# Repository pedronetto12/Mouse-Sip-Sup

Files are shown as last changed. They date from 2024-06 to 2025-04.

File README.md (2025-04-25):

# 🖱️ Mouse Inclusivo Sip-and-Puff

> Um projeto de tecnologia assistiva de **hardware e software abertos**, criado para promover **acessibilidade digital** com baixo custo.

## 💡 Sobre o Projeto

Este repositório apresenta o desenvolvimento de um **mouse controlado por sopro e sucção (Sip-and-Puff)**, pensado para pessoas com comprometimento motor severo e controle de cabeça preservado. O dispositivo permite o controle do cursor e cliques por meio de ações com a boca — como soprar ou sugar — utilizando componentes acessíveis e de baixo custo.

O projeto foi desenvolvido no ambiente universitário, com o objetivo de ser **gratuito, aberto e replicável**, fortalecendo o acesso democrático à tecnologia assistiva no Brasil.

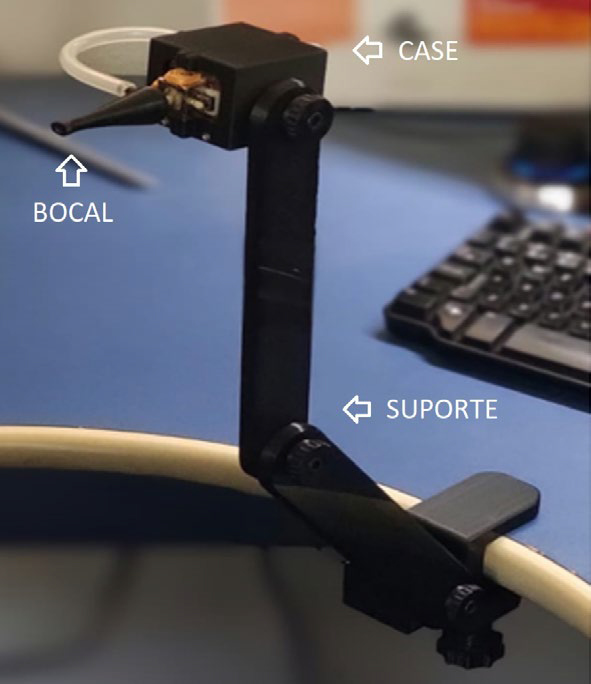
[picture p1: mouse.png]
Mouse Inclusivo Sip-and-Puff


## 🔧 Como Funciona

- **Joystick** detecta o movimento da cabeça do usuário.
- **Sensor de pressão** converte o sopro/sucção em sinais elétricos.
- **Arduino Pro Micro** interpreta os sinais e simula um mouse via USB.

| Ação com a boca | Função no mouse |
|---|---|
| Sopro forte | Clique esquerdo |
| Sucção forte | Clique direito |
| Sopro/sucção leve  | Rolagem de página |

## 📦 Componentes Principais

- Arduino Pro Micro (ATmega32U4)
- Sensor de pressão MPS20N0040D-S
- Módulo joystick KY-023
- Impressão 3D em PLA para a estrutura física

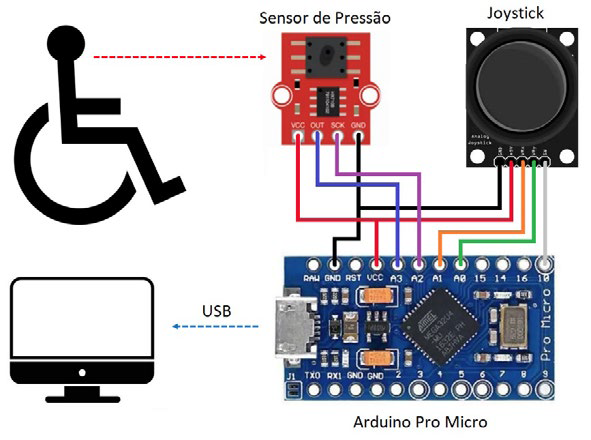
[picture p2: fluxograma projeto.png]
Fluxograma


## 📌 Objetivos

- 🧠 Promover **autonomia** e **inclusão digital**
- 🔓 Ser totalmente **open-source**
- 🤝 Incentivar a **inovação colaborativa**

## 📄 Publicação

Este projeto foi apresentado no **Congresso Brasileiro de Tecnologia Assistiva (CBTA)** como artigo técnico:

> **Grangeiro, Pedro Netto Gandolfi et al.** *Mouse inclusivo de hardware e software aberto controlado por sopro e sucção.* CBTA, 2023.

## 🛠️ Atualização no Design do Bocal

Realizamos uma **melhoria significativa no bocal** do dispositivo. Agora, o mouse conta com:

- 💨 **Ponta substituível**, garantindo mais higiene e praticidade no uso;
- 🦠 **Filtro antibactericida**, promovendo segurança em ambientes clínicos e domiciliares;
- 🔄 Projeto mais modular e de fácil substituição.

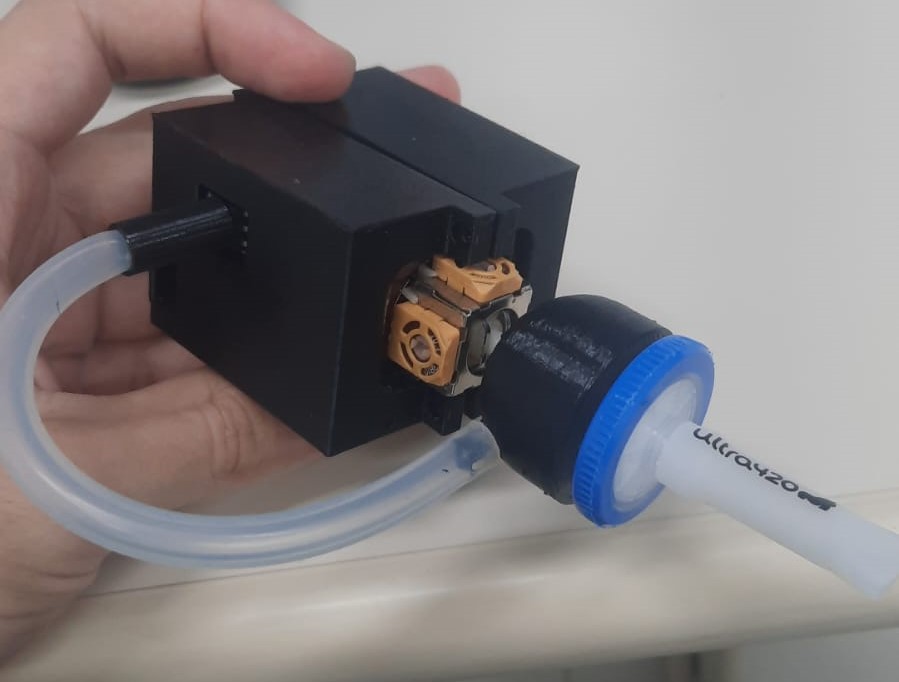
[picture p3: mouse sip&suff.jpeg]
Mouse Atualizado


Essa atualização reforça o compromisso do projeto com a usabilidade, segurança e conforto das pessoas com deficiência que irão utilizá-lo.

## 🤝 Agradecimentos

Agradecimentos à **UDESC** pelo suporte institucional e aos professores e colegas envolvidos.

## 📥 Contribua!

Quer contribuir? Tem ideias para melhorias? Fique à vontade para abrir uma issue ou enviar um pull request! Vamos juntos tornar a tecnologia mais inclusiva 💙

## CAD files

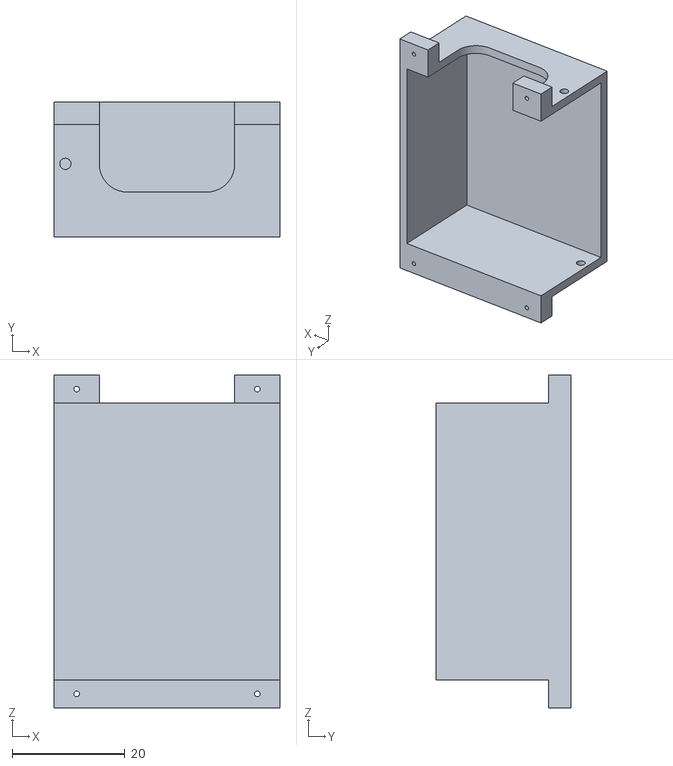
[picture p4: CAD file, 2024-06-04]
Arquivos de impressao mouse sip&sup/encaixe2 mouse.stl
40.0 x 24.0 x 59.0

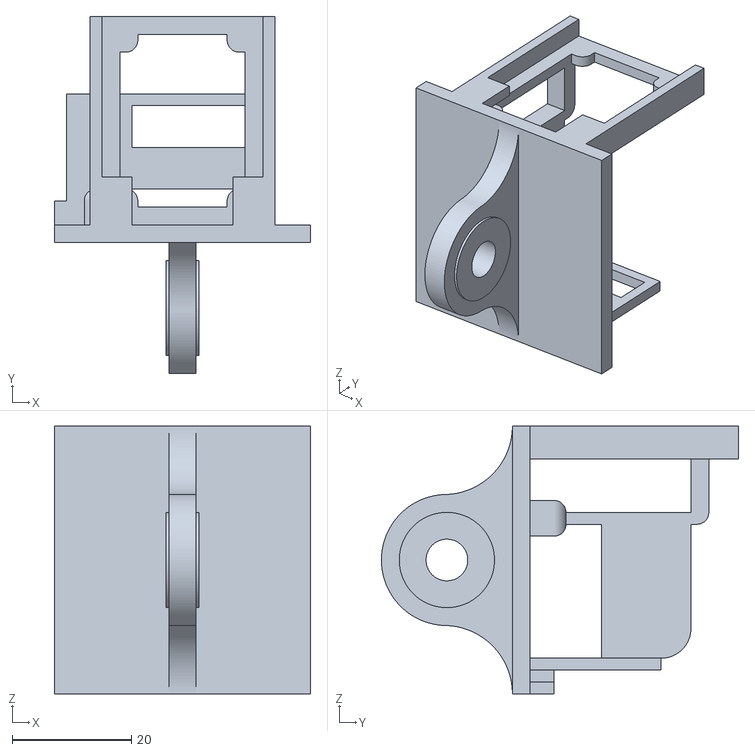
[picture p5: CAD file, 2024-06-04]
Arquivos de impressao mouse sip&sup/base mouse.stl
43.0 x 60.0 x 45.0

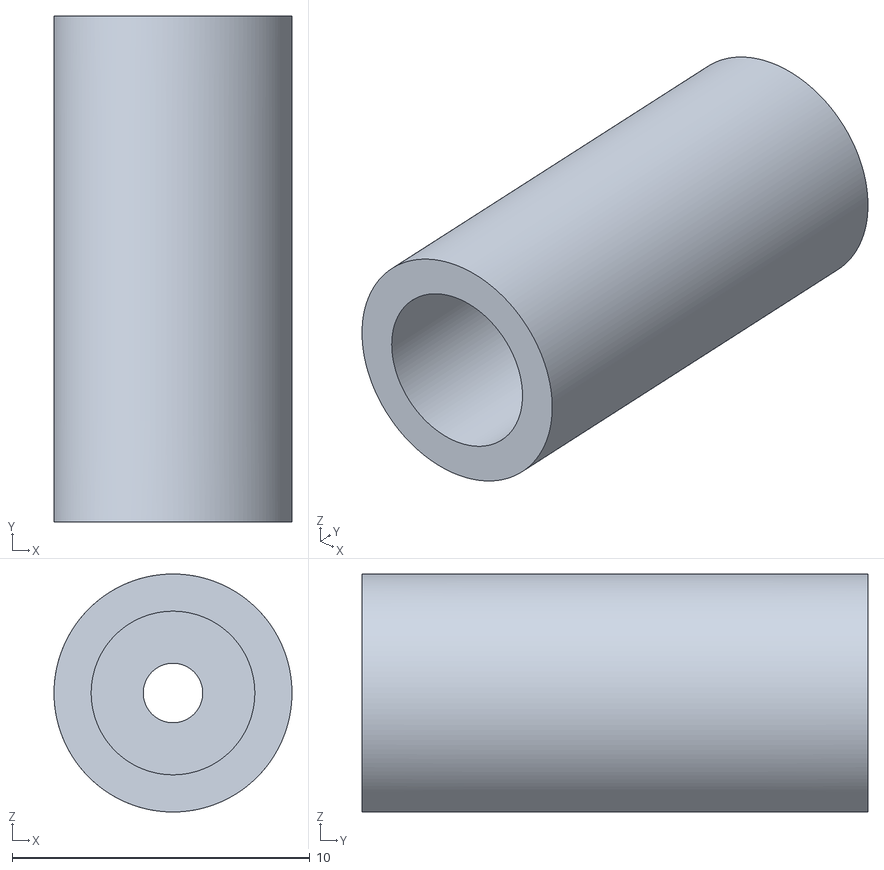
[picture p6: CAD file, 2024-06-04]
Arquivos de impressao mouse sip&sup/conexão tubo mouse.stl
8.00 x 17.0 x 8.00

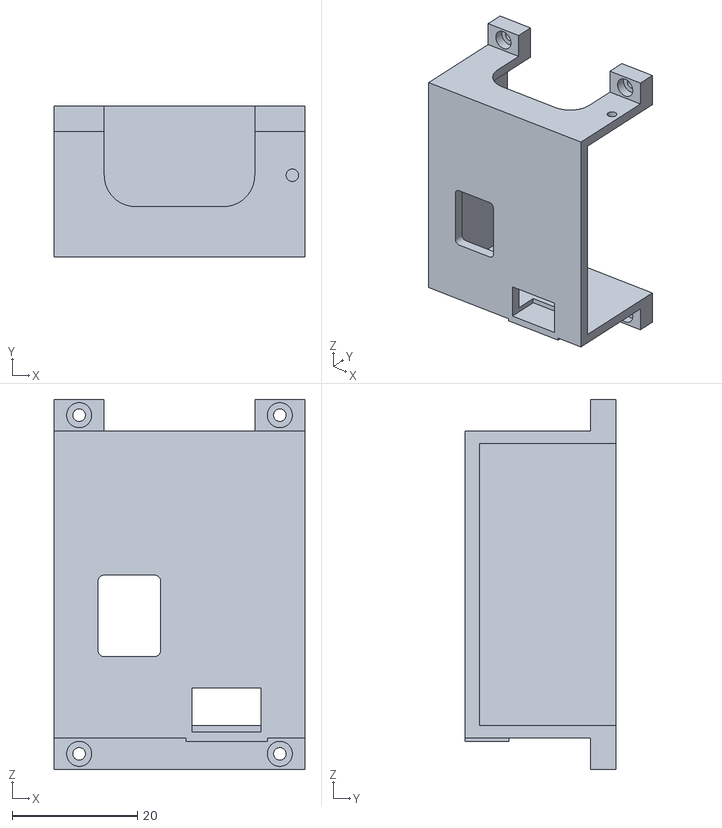
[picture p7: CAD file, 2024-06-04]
Arquivos de impressao mouse sip&sup/encaixe1 mouse.stl
40.0 x 24.0 x 59.0

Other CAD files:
Arquivos de impressao mouse sip&sup/acoplamento joystick.ipt
Arquivos de impressao mouse sip&sup/acoplamento joystick2.ipt
Arquivos de impressao mouse sip&sup/base mouse.ipt
Arquivos de impressao mouse sip&sup/conexão tubo mouse.ipt
Arquivos de impressao mouse sip&sup/encaixe1 mouse.ipt
Arquivos de impressao mouse sip&sup/encaixe2 mouse.ipt

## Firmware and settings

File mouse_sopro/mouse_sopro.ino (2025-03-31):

//----------------------bibliotecas----------------------
#include <Mouse.h>
#include <HX711_ADC.h> //https://github.com/olkal/HX711_ADC
#if defined(ESP8266)|| defined(ESP32) || defined(AVR)
#include <EEPROM.h>
#endif

//pins:
#define AxisX A1
#define AxisY A0
#define led0 3
#define led1 4
#define led2 5
#define led3 6
#define led4 7
#define led5 8
#define led6 9
#define led7 10
#define led8 16
#define led9 14
const int HX711_dout = 2; //mcu > HX711 dout pin, must be external interrupt capable!
const int HX711_sck = 15; //mcu > HX711 sck pin

//HX711 constructor:
HX711_ADC LoadCell(HX711_dout, HX711_sck);

//----------------------Variaveis----------------------
//parametros do HX711
float calibrationValue=2500; // calibration value
unsigned long stabilizingtime = 1000; // tare preciscion can be improved by adding a few seconds of stabilizing time
boolean _tare = true; //set this to false if you don't want tare to be performed in the next step
float dados_sensor=0;
volatile boolean newDataReady;



//parametros do joystick:
int range = 9;            // output range of X or Y movement
int threshold = range / 4;  // resting threshold
int center = range / 2;     // resting position value


//mouse
bool isLeftPressed = false;
bool isRightPressed = false;
int DELAY=0;


//LED
int ledState[10] = {0, 0, 0, 0, 0, 0, 0, 0, 0, 0};

//----------------------funções----------------------
void funcMouse(float ad);
void funcLED(float ad);
void pinLEDs();
void controlLED();
int readAxis(int thisAxis); //função leitura do analogico
void dataReadyISR();

void setup() {
  Serial.begin(57600);
  Serial.println("Starting...");
  LoadCell.setSamplesInUse(1);
  LoadCell.begin(); //config
  Mouse.begin(); //inicia funcionalidade das funções de mouse

  pinLEDs();

  LoadCell.start(stabilizingtime, _tare);//calibração
    if (LoadCell.getTareTimeoutFlag()) {
    Serial.println("Tempo limite, verifique a fiação MCU>HX711 e as designações dos pinos");
    while (1);
  }
  else {  
    LoadCell.setCalFactor(calibrationValue); // set calibration factor (float)
    Serial.println("Startup is complete");
  }
  attachInterrupt(digitalPinToInterrupt(HX711_dout), dataReadyISR, FALLING);
}

void loop() {  
  
  if (newDataReady) {
    newDataReady = 0;
    dados_sensor=LoadCell.getData();
    Serial.print(dados_sensor);
    Serial.print("\t");
    funcMouse(dados_sensor);
    funcLED(dados_sensor);
    controlLED();
  }
  
  Mouse.move(-readAxis(AxisX), readAxis(AxisY), 0);//movimento seta
  delay(10);
}

void funcMouse(float ad){  
 if (ad < -650) { //Hard sip
      if (!isRightPressed) {
        Mouse.press(MOUSE_RIGHT);
        isRightPressed = true;
        Serial.println("ok1");
      }
    } 
    else if (ad >= -650 && ad < -100 ) { //Soft sip
      DELAY++;
      if(DELAY>4){Mouse.move(0, 0, -1);Serial.println("ok2");}
    } 
    else if (ad >= -100 && ad <= 100) { //se estiver no meio, solta os dois botões
      DELAY=0;
      if (isLeftPressed) {Mouse.release(MOUSE_LEFT);isLeftPressed = false;}
      if (isRightPressed) {Mouse.release(MOUSE_RIGHT);isRightPressed = false;}
      Serial.println("ok3");
    } 
    
    else if (ad > 100 && ad <= 650) { //Soft puff
      DELAY++;
      if(DELAY>4){Mouse.move(0, 0, 1);Serial.println("ok4");}
    } 
    
    else if (ad > 650) { //Hard puff
      if (!isLeftPressed) {
        Mouse.press(MOUSE_LEFT);
        isLeftPressed = true;
        Serial.println("ok5");
      }
    }
}

void funcLED(float ad){
  if (ad<=-800){         ledState[0] = 1;ledState[1] = 0;ledState[2] = 0;ledState[3] = 0;ledState[4] = 0;ledState[5] = 0;ledState[6] = 0;ledState[7] = 0;ledState[8] = 0;ledState[9] = 0;}
  if (ad>-800&&ad<=-600){ledState[0] = 1;ledState[1] = 1;ledState[2] = 0;ledState[3] = 0;ledState[4] = 0;ledState[5] = 0;ledState[6] = 0;ledState[7] = 0;ledState[8] = 0;ledState[9] = 0;}
  if (ad>-600&&ad<=-400){ledState[0] = 1;ledState[1] = 1;ledState[2] = 1;ledState[3] = 0;ledState[4] = 0;ledState[5] = 0;ledState[6] = 0;ledState[7] = 0;ledState[8] = 0;ledState[9] = 0;}
  if (ad>-200&&ad<=-50){ ledState[0] = 1;ledState[1] = 1;ledState[2] = 1;ledState[3] = 1;ledState[4] = 0;ledState[5] = 0;ledState[6] = 0;ledState[7] = 0;ledState[8] = 0;ledState[9] = 0;}
  if (ad>-50&&ad<=50){   ledState[0] = 1;ledState[1] = 1;ledState[2] = 1;ledState[3] = 1;ledState[4] = 1;ledState[5] = 0;ledState[6] = 0;ledState[7] = 0;ledState[8] = 0;ledState[9] = 0;}
  if (ad>50&&ad<=200){   ledState[0] = 1;ledState[1] = 1;ledState[2] = 1;ledState[3] = 1;ledState[4] = 1;ledState[5] = 1;ledState[6] = 0;ledState[7] = 0;ledState[8] = 0;ledState[9] = 0;}
  if (ad>200&&ad<400){   ledState[0] = 1;ledState[1] = 1;ledState[2] = 1;ledState[3] = 1;ledState[4] = 1;ledState[5] = 1;ledState[6] = 1;ledState[7] = 0;ledState[8] = 0;ledState[9] = 0;}
  if (ad>400&&ad<600){   ledState[0] = 1;ledState[1] = 1;ledState[2] = 1;ledState[3] = 1;ledState[4] = 1;ledState[5] = 1;ledState[6] = 1;ledState[7] = 1;ledState[8] = 0;ledState[9] = 0;}
  if (ad>600&&ad<800){   ledState[0] = 1;ledState[1] = 1;ledState[2] = 1;ledState[3] = 1;ledState[4] = 1;ledState[5] = 1;ledState[6] = 1;ledState[7] = 1;ledState[8] = 1;ledState[9] = 0;}
  if (ad>=800){          ledState[0] = 1;ledState[1] = 1;ledState[2] = 1;ledState[3] = 1;ledState[4] = 1;ledState[5] = 1;ledState[6] = 1;ledState[7] = 1;ledState[8] = 1;ledState[9] = 1;}
}

void pinLEDs(){
  pinMode(led0, OUTPUT);
  pinMode(led1, OUTPUT);
  pinMode(led2, OUTPUT);
  pinMode(led3, OUTPUT);
  pinMode(led4, OUTPUT);
  pinMode(led5, OUTPUT);
  pinMode(led6, OUTPUT);
  pinMode(led7, OUTPUT);
  pinMode(led8, OUTPUT);
  pinMode(led9, OUTPUT);
}

void controlLED(){
  digitalWrite(3, ledState[0]);
  digitalWrite(4, ledState[1]);
  digitalWrite(5, ledState[2]);
  digitalWrite(6, ledState[3]);
  digitalWrite(7, ledState[4]);
  digitalWrite(8, ledState[5]);
  digitalWrite(9, ledState[6]);
  digitalWrite(10, ledState[7]);
  digitalWrite(16, ledState[8]);
  digitalWrite(14, ledState[9]);
}

int readAxis(int thisAxis) {
  // read the analog input:
  int reading = analogRead(thisAxis);

  // map the reading from the analog input range to the output range:
  reading = map(reading, 0, 1023, 0, range);

  // if the output reading is outside from the rest position threshold, use it:
  int distance = reading - center;

  if (abs(distance) < threshold) {  //zona morta
    distance = 0;
  }

  // return the distance for this axis:
  return distance;
}

//interrupt routine:
void dataReadyISR() {
  if (LoadCell.update()) {
    newDataReady = 1;
  }
}
